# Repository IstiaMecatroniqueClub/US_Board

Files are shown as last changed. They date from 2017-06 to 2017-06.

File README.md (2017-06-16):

# Istia Mecatronique Club - US Board

## Synopsis

This repository contains the source codes and the schematics of our US board. This board has an Ultra-Sound sensor and a CAN bus interface, controlled by an ATMega 32m1.

## Repository architecture

This repository contains a "board" folder with the schematics of the board, a "code" folder with the source code of the ATMega and a "documentation" folder with the doxygen documentation of the source code.

## The source code

### How does it work

The board waits for a remote request CAN message with the IDMSGCAN identifier (0x0C0), then returns a data CAN message with the same identifier and the sensor value (the distance over 2 bytes). Note that the board can also return an error value (if the returned distance is 0, 1 or 2 it means that an error occured).

### The files

The "code/include" folder contains 
 - a Pin interface class to handle a pin on the ATMega (this class sould not be instanciated)
 - an Input class to handle an input pin
 - an Ouput class to handle an output pin
 - a Led class to handle an led connected to the ATMega
 - a Hcrs04 class to handle the US sensor
 - a Timer class to handle timers in the ATMega

### The ATMega output.hex file
In the code folder you can find a Makefile to generate the binary *.hex file and upload it to the ATMega. The makefile is configured for
 - avrdude compiler ( $ sudo apt-get install avrdude avr-libc)
 - AVRispmkII programmer

Then do
 - $ make hex # to generate the binary ouput.hex
 - $ make upload # to upload the output.hex file to the ATMega
 - $ make all  # to compile and then upload 

This has been tester with Ubuntu and Lubuntu on a raspberry pi 3.

## The documentation
We use Doxygen to generate the documentation of the source code. By using the makefile (in the code folder) you can do
 - $ make documentation
To generate the documentation files.

Note that you need to have doxygen and graphviz (for the graphs) installed
 - $ sudo apt-get install doxygen
 - $ sudo apt-get install graphviz

## Tests

When powering the board, the LED should blink a few times and then stop.

## License

GNU General Public License v3.0.

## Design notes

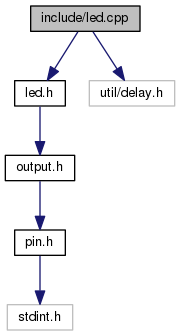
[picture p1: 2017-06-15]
documentation/html/led_8cpp__incl.png

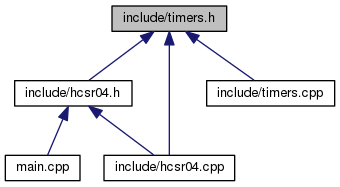
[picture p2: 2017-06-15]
documentation/html/timers_8h__dep__incl.png

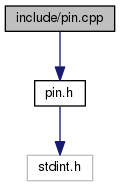
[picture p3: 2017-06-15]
documentation/html/pin_8cpp__incl.png

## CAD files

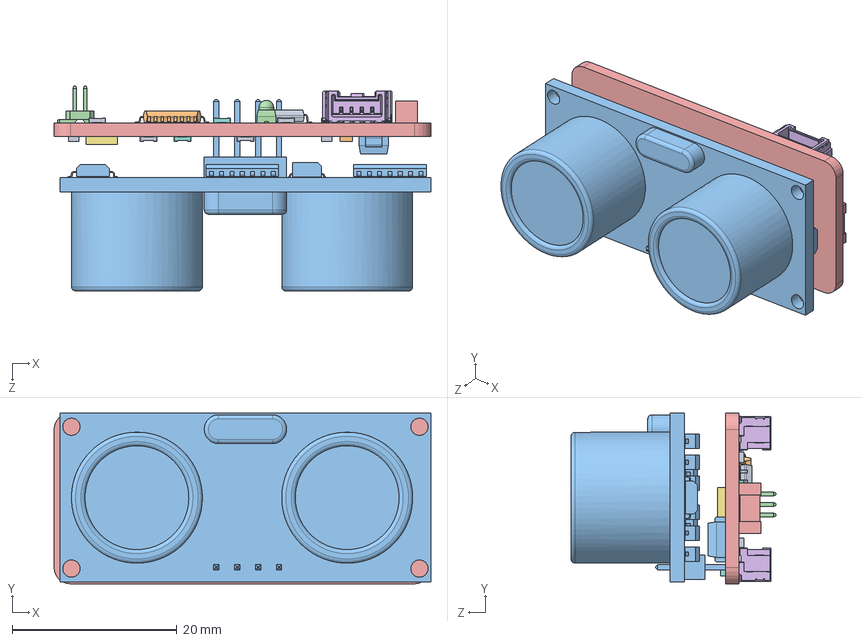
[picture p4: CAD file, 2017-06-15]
board/Solidworks/ultrasonic_sensor.SLDASM
45.7 x 20.7 x 24.9 mm
C2012 x 8
EIA3216
403A-03
VLD
EIARS-481-2
SMD_KX7_16MHZ
R2012 x 3
SOIC8
TQFP32
HC-SR04
MINITEK_127_6WAY_SMD_MINITEK_6WAY
Carte

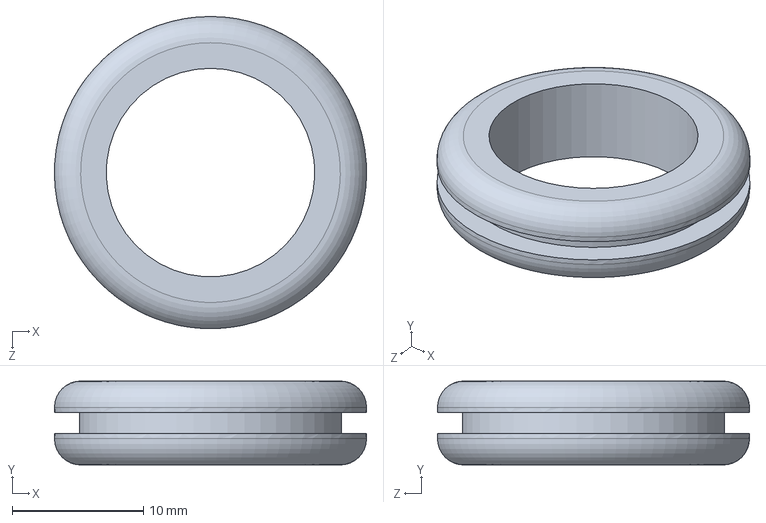
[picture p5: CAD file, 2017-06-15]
board/Solidworks/PV73MGROMMETPK100.SLDPRT
23.8 x 6.40 x 23.8 mm

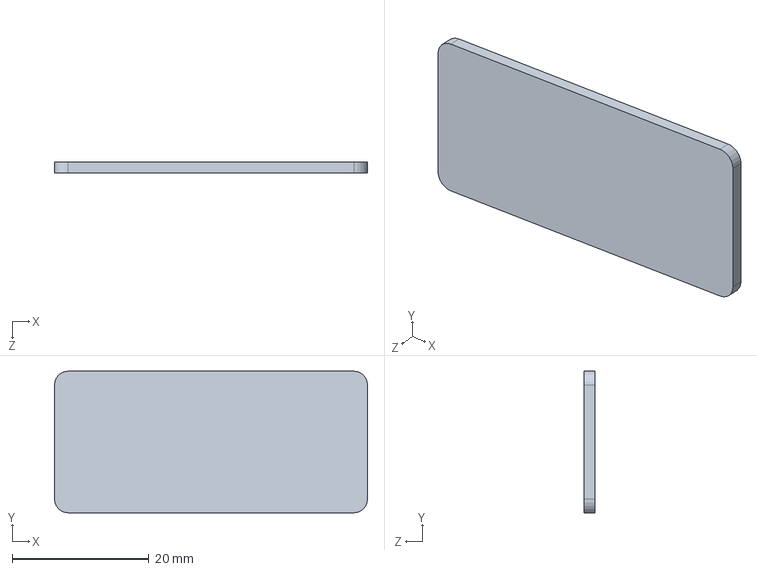
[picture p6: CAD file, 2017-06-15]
board/Solidworks/Carte.SLDPRT
45.7 x 20.7 x 1.60 mm

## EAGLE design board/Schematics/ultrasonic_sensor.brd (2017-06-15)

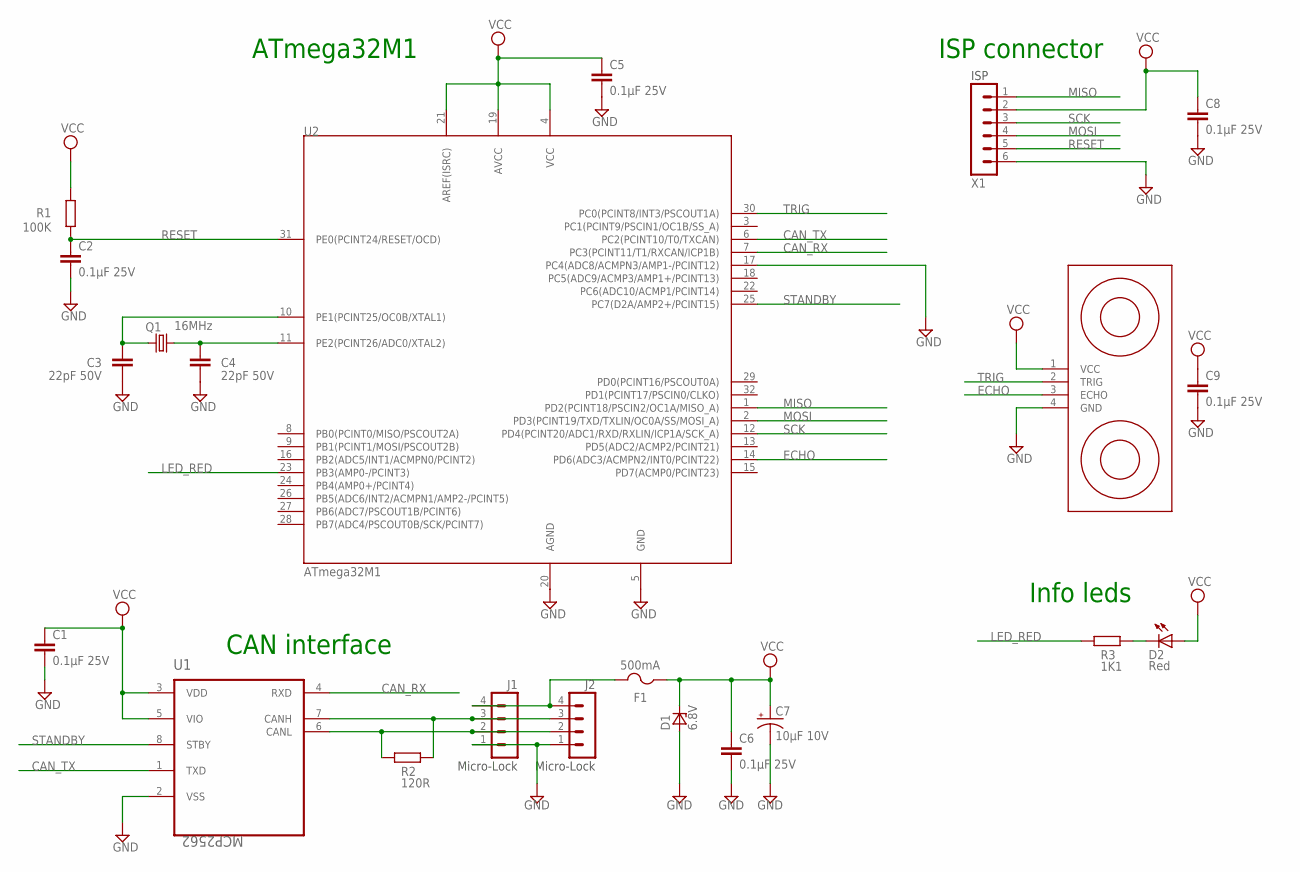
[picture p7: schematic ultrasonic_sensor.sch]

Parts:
C1, C2, C5, C6, C8, C9: 0.1µF 25V; C2012
C3, C4: 22pF 50V; C2012
C7: 10µF 10V; EIA3216
D1: 6.8V; DO-214AA
D2: Red; VLD
F1: 500mA; EIARS-481-2
J1, J2: Micro-Lock; 504195-0470
Q1: 16MHz; SMD_KX7
R1: 100K; R2012
R2: 120R; R2012
R3: 1K1; R2012
U1: MCP2562; SOIC8
U2: ATmega32M1; TQFP32
U3: HC-SR04; ULTRASONIC-HC-SR04
X1: ISP; MINITEK_127_6WAY_SMD

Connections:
CAN_RX: U1.4 (RXD), U2.7 (PC3(PCINT11/T1/RXCAN/ICP1B))
CAN_TX: U1.1 (TXD), U2.6 (PC2(PCINT10/T0/TXCAN))
ECHO: U2.14 (PD6(ADC3/ACMPN2/INT0/PCINT22)), U3.3 (ECHO)
GND: C1.2, C2.2, C3.2, C4.2, C5.2, C6.2, C7.C (-), C8.2, C9.2, D1.A, J1.1, J2.1, U1.2 (VSS), U2.5 (GND), U2.17 (PC4(ADC8/ACMPN3/AMP1-/PCINT12)), U2.20 (AGND), U3.4 (GND), X1.6
LED_RED: R3.2, U2.23 (PB3(AMP0-/PCINT3))
MISO: U2.1 (PD2(PCINT18/PSCIN2/OC1A/MISO_A)), X1.1
MOSI: U2.2 (PD3(PCINT19/TXD/TXLIN/OC0A/SS/MOSI_A)), X1.4
unnamed: D2.C, R3.1
unnamed: F1.2, J1.4, J2.4
unnamed: J1.2, J2.2, R2.2, U1.6 (CANL)
unnamed: J1.3, J2.3, R2.1, U1.7 (CANH)
unnamed: C4.1, Q1.3 (2), U2.11 (PE2(PCINT26/ADC0/XTAL2))
unnamed: C3.1, Q1.1, U2.10 (PE1(PCINT25/OC0B/XTAL1))
RESET: C2.1, R1.1, U2.31 (PE0(PCINT24/RESET/OCD)), X1.5
SCK: U2.12 (PD4(PCINT20/ADC1/RXD/RXLIN/ICP1A/SCK_A)), X1.3
STANDBY: U1.8 (STBY), U2.25 (PC7(D2A/AMP2+/PCINT15))
TRIG: U2.30 (PC0(PCINT8/INT3/PSCOUT1A)), U3.2 (TRIG)
VCC: C1.1, C5.1, C6.1, C7.A (+), C8.1, C9.1, D1.C, D2.A, F1.1, R1.2, U1.3 (VDD), U1.5 (VIO), U2.4 (VCC), U2.19 (AVCC), U2.21 (AREF(ISRC)), U3.1 (VCC), X1.2

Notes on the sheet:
ISP connector
Info leds
CAN interface
ATmega32M1

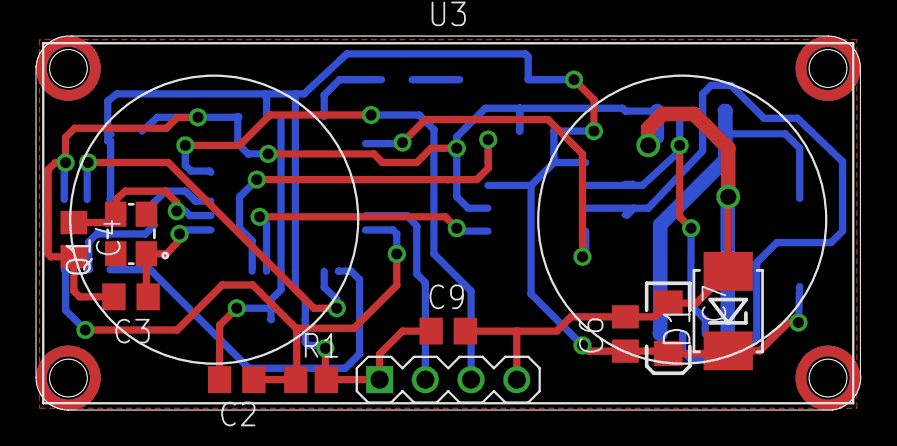
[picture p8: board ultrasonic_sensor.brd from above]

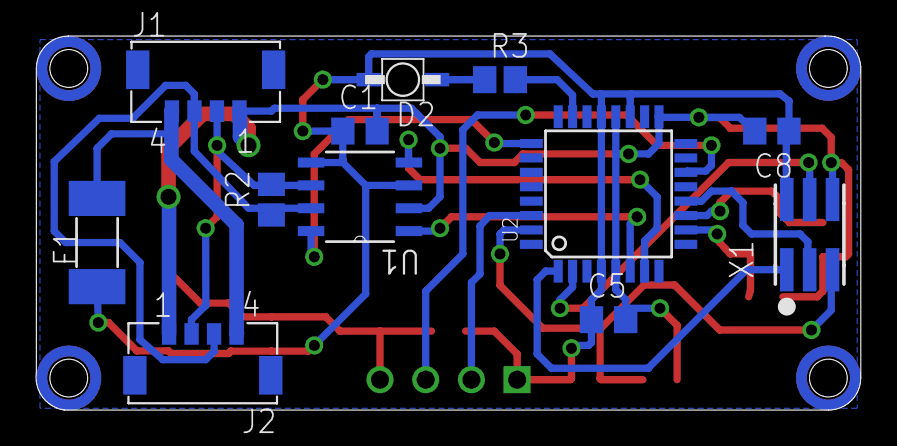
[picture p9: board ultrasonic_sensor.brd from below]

Board: 2 copper layers, 45.8 x 20.8 mm, 23 parts (12 on the bottom side), 18 nets.

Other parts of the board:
DRILEGEND: DRILEGEND

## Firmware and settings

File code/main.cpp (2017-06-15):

//! \file main.cpp
//! \brief Main file
//! \author Baptiste Hamard,Franck Mercier, Remy Guyonneau
//! \date 2017 04 24
//!
//! Main file for the US card. To change the Ultra Sound identifier, just change the IDMSCAN constant before generating the .hex file.
#define FOSC           16000
#define F_CPU          16000000UL

#include <avr/io.h>
#include <avr/interrupt.h>
#include "hcsr04.h"
#include "led.h"

// Configuration declaration for the LED wiring
#define LED_RED_PORT PORTB //!< The ATMega port where the red LED is wired
#define LED_RED_PIN  3     //!< The ATMega pin where the red LED is wired
#define LED_RED_POL  0     //!< The polarity of the red LED


// Configuration declaration for the LED wiring
#define US_TRIG_PORT    PORTC //!< The ATMega port where the trigger of the US is wired
#define US_TRIG_PIN     0     //!< The ATMega port where the trigger of the US is wired
#define US_ECHO_PORT    PORTD //!< The ATMega port where the echo of the US is wired
#define US_ECHO_PIN     6     //!< The ATMega port where the echo of the US is wired


#define IDMSGCAN 0x0C0 //!< the identifier of the US card

//! \fn void initCANBus()
//! \brief Intialize the CAN Bus.
//!
//! Function that initializes the CANBus according to the wiring and the needed speed (500kb/s).
//! It also enable the CAN module interruptions
void initCANBus(){
	// Enable of CAN transmit
	DDRC|=0x80; // Configuration of the standby pin as an output
	// (for a transceiver MCP2562 with the stby pin wired to the uC PC7)
	// Enable the MCP2562 (STANDBY to 0)
	PORTC &= 0x7F; // Activation of the MCP2562
	// (for a transceiver MCP2562 with the stby pin wired to the uC PC7)

	// Initialization of CAN module
	CANGCON  = (1 << SWRES); // Reset CAN module
	CANGCON  = 0x02; // Enable CAN module

	CANBT1 = 0x06; // Speed Config (500kb/s)
	CANBT2 = 0x04;
	CANBT3 = 0x13;

	CANHPMOB = 0x00; // No priority between the CAN MOB

	// Enable CAN interruptions and especially reception interruptions
	CANGIE |= 0xA0;
}

//! \fn void initCANMOB()
//! \brief Intialize the CAN MOB.
//!
//! Intialize the CAN MOB. A MOB can be seen as a "CAN socket".
//! In this case the MOB1 is used to receive remote request
//! and MOB0 is used to send the Ultra sound value
void initCANMOB(){
	CANPAGE = 0x10; // selection of MOB1 (reveice request)

	CANIDT4 = 0x04; // Config as reception remote (rtr = 1)
	CANIDT3 = 0x00;
	CANIDT2 = (uint8_t)( (IDMSGCAN & 0x00F)<< 5 ); // using the constant to configure the remote request identifier
	CANIDT1 = (uint8_t)( IDMSGCAN >> 3 );

	CANIDM4 = 0x04; // mask over the rtr value
	CANIDM3 = 0xFF; // mask over the identifier (we only want an interruption if the received CAN message is a remote request with the corresponding identifier)
	CANIDM2 = 0xFF;
	CANIDM1 = 0xFF;

	CANCDMOB = 0x80; // Config MOB as reception
	
	CANIE2 = 0x02; // enable the interruptions over the MOB 1

	sei(); // set enable interruption
}

Hcsr04 us_sensor(Output(&US_TRIG_PORT, US_TRIG_PIN), Input(&US_ECHO_PORT, US_ECHO_PIN)); //!< The Ultra Sound Sensor
Led led(&LED_RED_PORT, LED_RED_PIN, LED_RED_POL); //!< The RED Led

int main(void) {
	for(int i=0; i<4; i++){
		led.blink(100);
	}

	initCANBus(); // intialization of the CAN Bus
	initCANMOB(); // intialization of the CAN MOB

	while(1){
	}
}


//! \fn ISR(CAN_INT_vect)
//! \brief CAN interruption.
//! This function is called when an CAN interruption is raised.
//! When it appens, the US sensor value is readed and sent using the MOB 0
ISR(CAN_INT_vect){
	cli(); // disable the interruption (no to be disturbed when dealing with one)

	led.blink(50); // blink the LED

	CANPAGE = 0x10; // Selection of MOB 1
	CANSTMOB = 0x00; // Reset the status of the MOB
	CANCDMOB = 0x80; // Config as reception MOB
	CANIE2 = 0x02; // Enable the interuption over MOB 1 (for the next one)

	uint16_t dst = us_sensor.getDistance(); // get the distance of the Ultra Sound Sensor

	CANPAGE  = 0x00; //Selection of MOB 0

	CANIDT4 = 0x00; // Config as data (rtr = 0)
	CANIDT3 = 0x00;
	CANIDT2 = (uint8_t)( (IDMSGCAN & 0x00F)<< 5 ); // use the same identifier as the remote request
	CANIDT1 = (uint8_t)( IDMSGCAN >> 3 );

	CANMSG = (uint8_t)( (dst & 0xFF00) >> 8 ); // update the first byte of the CAN message data
	CANPAGE = 0x01; // move to next index for CANMSG (canpage : MOB|INDEX) (next byte of the data)
	CANMSG = (uint8_t)( dst & 0x00FF ); // update the second byte of the CAN message data

	CANCDMOB = 0x42; // send the message using the MOB 0

	sei(); // enable the interruptions
}

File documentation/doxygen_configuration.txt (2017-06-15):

# Doxyfile 1.8.11

#---------------------------------------------------------------------------
# Project related configuration options
#---------------------------------------------------------------------------
DOXYFILE_ENCODING      = UTF-8
PROJECT_NAME           = "IstiaBOT - US Board"
PROJECT_NUMBER         = 
PROJECT_BRIEF          = 
PROJECT_LOGO           = ../documentation/logo.png
OUTPUT_DIRECTORY       = 
CREATE_SUBDIRS         = NO
ALLOW_UNICODE_NAMES    = NO
OUTPUT_LANGUAGE        = English
BRIEF_MEMBER_DESC      = YES
REPEAT_BRIEF           = YES
ABBREVIATE_BRIEF       = "The $name class" \
                         "The $name widget" \
                         "The $name file" \
                         is \
                         provides \
                         specifies \
                         contains \
                         represents \
                         a \
                         an \
                         the
ALWAYS_DETAILED_SEC    = NO
INLINE_INHERITED_MEMB  = NO
FULL_PATH_NAMES        = YES
STRIP_FROM_PATH        = 
STRIP_FROM_INC_PATH    = 
SHORT_NAMES            = NO
JAVADOC_AUTOBRIEF      = NO
QT_AUTOBRIEF           = NO
MULTILINE_CPP_IS_BRIEF = NO
INHERIT_DOCS           = YES
SEPARATE_MEMBER_PAGES  = NO
TAB_SIZE               = 4
ALIASES                = 
TCL_SUBST              = 
OPTIMIZE_OUTPUT_FOR_C  = NO
OPTIMIZE_OUTPUT_JAVA   = NO
OPTIMIZE_FOR_FORTRAN   = NO
OPTIMIZE_OUTPUT_VHDL   = NO
EXTENSION_MAPPING      = 
MARKDOWN_SUPPORT       = YES
AUTOLINK_SUPPORT       = YES
BUILTIN_STL_SUPPORT    = NO
CPP_CLI_SUPPORT        = NO
SIP_SUPPORT            = NO
IDL_PROPERTY_SUPPORT   = YES
DISTRIBUTE_GROUP_DOC   = NO
GROUP_NESTED_COMPOUNDS = NO
SUBGROUPING            = YES
INLINE_GROUPED_CLASSES = NO
INLINE_SIMPLE_STRUCTS  = NO
TYPEDEF_HIDES_STRUCT   = NO
LOOKUP_CACHE_SIZE      = 0
#---------------------------------------------------------------------------
# Build related configuration options
#---------------------------------------------------------------------------
EXTRACT_ALL            = YES
EXTRACT_PRIVATE        = YES
EXTRACT_PACKAGE        = NO
EXTRACT_STATIC         = YES
EXTRACT_LOCAL_CLASSES  = YES
EXTRACT_LOCAL_METHODS  = NO
EXTRACT_ANON_NSPACES   = NO
HIDE_UNDOC_MEMBERS     = NO
HIDE_UNDOC_CLASSES     = NO
HIDE_FRIEND_COMPOUNDS  = NO
HIDE_IN_BODY_DOCS      = NO
INTERNAL_DOCS          = NO
CASE_SENSE_NAMES       = NO
HIDE_SCOPE_NAMES       = NO
HIDE_COMPOUND_REFERENCE= NO
SHOW_INCLUDE_FILES     = YES
SHOW_GROUPED_MEMB_INC  = NO
FORCE_LOCAL_INCLUDES   = NO
INLINE_INFO            = YES
SORT_MEMBER_DOCS       = YES
SORT_BRIEF_DOCS        = NO
SORT_MEMBERS_CTORS_1ST = NO
SORT_GROUP_NAMES       = NO
SORT_BY_SCOPE_NAME     = NO
STRICT_PROTO_MATCHING  = NO
GENERATE_TODOLIST      = YES
GENERATE_TESTLIST      = YES
GENERATE_BUGLIST       = YES
GENERATE_DEPRECATEDLIST= YES
ENABLED_SECTIONS       = 
MAX_INITIALIZER_LINES  = 30
SHOW_USED_FILES        = YES
SHOW_FILES             = YES
SHOW_NAMESPACES        = YES
FILE_VERSION_FILTER    = 
LAYOUT_FILE            = 
CITE_BIB_FILES         = 
#---------------------------------------------------------------------------
# Configuration options related to warning and progress messages
#---------------------------------------------------------------------------
QUIET                  = NO
WARNINGS               = YES
WARN_IF_UNDOCUMENTED   = YES
WARN_IF_DOC_ERROR      = YES
WARN_NO_PARAMDOC       = NO
WARN_AS_ERROR          = NO
WARN_FORMAT            = "$file:$line: $text"
WARN_LOGFILE           = 
#---------------------------------------------------------------------------
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

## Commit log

2017-06-15 Adding Board folder
    [Carte.SLDPRT, PV73MGROMMETPK100.SLDPRT, ultrasonic_sensor.SLDASM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]
2017-06-15 Adding source code
    [Carte.SLDPRT, PV73MGROMMETPK100.SLDPRT, doxygen_configuration.txt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]
